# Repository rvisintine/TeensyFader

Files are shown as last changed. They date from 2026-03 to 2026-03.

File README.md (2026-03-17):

# USB MIDI Crossfader

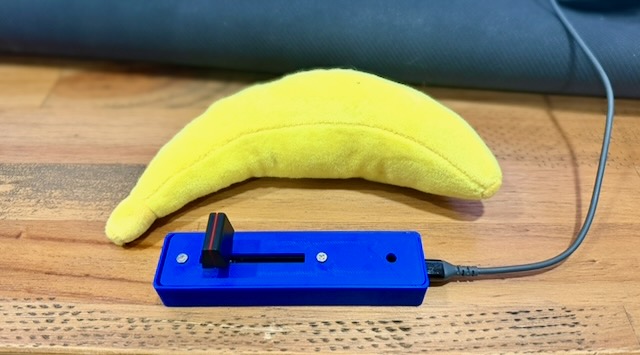
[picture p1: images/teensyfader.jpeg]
Teensy Fader


I wanted a simple MIDI crossfader for using with Traktor and Ableton.  I couldn't find anything I liked so decided to build my own.  The Mini Innofader Plus I used is way overkill, you could swap it out with something cheaper. It should work just fine with the Teensy code as is, you'd just need to tweak the case to fit whatever you buy.  You'll need some basic soldering tools and skills, and a 3d printer to complete this project.

## Materials

To build this you'll need to buy
Mini Innofader Plus ($115 shipped) [innofader.com](https://www.innofader.com/products.php?id=24)

Teensy 4.0 (without pins) ~$23 [sparkfun.com](https://www.sparkfun.com/teensy-4-0.html) |

Optional:
WS2812B NeoPixel LED (single)
Adhesive rubber feet

## Wiring

The Mini Innofader Plus includes multiple harnesses.  I used one of the 3-wire harnesses (gray, green, blue). The fader has
auto-sensing polarity, so the outer two wires (VCC/GND) can be swapped without damage.
The center wire (green) is always the wiper/signal.

| Wire | Color | Teensy 4.0 Pin |
|---|---|---|
| VCC | Gray | 3.3V |
| Wiper (signal) | Green (center) | A0 (pin 14) |
| GND | Blue | GND |

**WS2812B LED** (optional):

| LED Wire | Teensy 4.0 Pin |
|---|---|
| GND | GND |
| DIN (data in) | Pin 2 |
| VCC | 3.3V |

## Firmware

### Requirements

- [Arduino IDE](https://www.arduino.cc/en/software)
- [Teensyduino](https://www.pjrc.com/teensy/td_download.html) add-on — follow the install guide on the Teensyduino page for your platform
- [Adafruit NeoPixel](https://github.com/adafruit/Adafruit_NeoPixel) library — Arduino IDE may prompt to install this automatically when you open the sketch; otherwise install via **Sketch > Include Library > Manage Libraries**
### Flashing

1. Open `firmware/crossfader.ino` in Arduino IDE
2. Select **Board: Teensy 4.0**
3. Select **USB Type: Serial + MIDI**
4. Click Upload

### Configuration (via Serial)

Settings can be changed in code before uploading, or can be changed over serial and saved to EEPROM (persists across power cycles).
Open any serial terminal at 9600 baud — Arduino Serial Monitor works fine.

When connected, the device prints its current config automatically.

| Command | Description |
|---|---|
| `channel <1-16>` | Set MIDI channel |
| `cc <0-127>` | Set fader CC number |
| `ledcc <0-127>` | Set incoming CC number for LED color |
| `status` | Print current config |

## Testing

Once the firmware is flashed and the fader is wired up, you can validate that everything
works before connecting to your software.

### MIDI Monitor

[MIDI Monitor](https://www.snoize.com/midimonitor/) is a free macOS app that displays
all incoming MIDI messages in real time.  You should be able to use something like MidiView for PC.

1. Install and open MIDI Monitor
2. Plug in the Teensy via USB — it should appear as a MIDI source named "Teensy MIDI"
3. Select the source in MIDI Monitor's sources list
4. Move the fader — you should see **Control Change** messages scrolling as you move it
5. The CC number and channel should match your configured values (defaults: CC 4, channel 20)
6. Values should range smoothly from 0 (one end) to 127 (other end)

### Troubleshooting

- **No MIDI device appears** — make sure the firmware was flashed with **USB Type: Serial + MIDI**. If you used a different USB type, reflash with the correct setting.
- **Device appears but no messages** — check the wiring. The signal wire (green/center) must be connected to **A0**. Verify VCC and GND are connected to **3.3V** and **GND**.
- **Values jump or are noisy** — this can indicate a loose solder joint on the wiper (signal) wire. Reflow the connection.
- **Values only go partway** — the fader travel may not reach the full range. This is normal for some innofader models and can be adjusted in the firmware's ADC mapping if needed.
- **Teensy not recognized by macOS** — try a different USB cable (some cables are charge-only with no data lines). Try a different USB port.

## Enclosure

Open `enclosure/crossfader_case.scad` in [OpenSCAD](https://openscad.org/) to render and export STL files.

The enclosure is a two-piece design:

- **Base** — full-height box with internal support for the lid, USB port cutout, and a friction-fit Teensy cradle with L-shaped rails and SMD clearance underneath
- **Lid** — hollow shell with fader slot, M3 mounting holes, and optional LED hole; drops into the base

All dimensions are parametric — adjust fader and Teensy measurements at the top of the SCAD file to fit your specific components.

### Print Settings

- Layer height: 0.2mm
- Infill: 20%
- Material: PLA or PETG
- Supports: none needed (both pieces print flat)

**Bambu Studio note:** After importing the STL, split the parts and flip the lid 180 degrees so the top surface sits flat on the build plate. The SCAD file exports both pieces upright, but the lid needs to print top-down.

## RGB LED (Optional)

The LED lights red on power-up. Software (e.g., Traktor) can change the color by sending
a MIDI CC message back to the device on the configured LED CC number (default: CC 2).

| CC Value | Color |
|---|---|
| 0-15 | Red |
| 16-31 | Green |
| 32-47 | Blue |
| 48-63 | Yellow |
| 64-79 | Cyan |
| 80-95 | Magenta |
| 96-111 | White |
| 112-127 | Off |

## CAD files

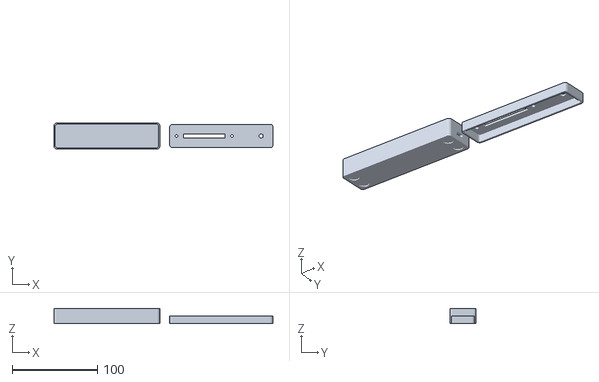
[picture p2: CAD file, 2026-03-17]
enclosure/crossfader_case.stl
256.5 x 30.4 x 18.0

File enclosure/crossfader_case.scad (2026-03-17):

// USB MIDI Crossfader — Enclosure
// Two-piece snap-fit case for Mini Innofader Plus + Teensy 4.0
// Print both pieces flat (no supports needed).
//
// Units: mm

// --- Dimensions (adjust to match your specific Innofader Plus) ---
fader_slot_length = 49;       // fader knob travel opening
fader_slot_width  = 5;        // width of the slot for the knob
fader_mount_spacing = 65;     // screw hole center-to-center (~1.5")
fader_mount_hole_dia = 3.2;   // M3 screw clearance
fader_body_length = 73;       // fader PCB length (along travel axis)
fader_body_width  = 16;       // fader PCB width

// Teensy 4.0 dimensions (without pins — soldering wires directly)
teensy_length = 36.3;
teensy_width  = 17.4;
teensy_height = 4;            // no pins, board + components only
usb_width     = 8;            // micro-USB port opening
usb_height    = 3.0;            // micro-USB port height

// Teensy cradle parameters
teensy_cradle_tolerance = 0.3;      // gap per side for friction fit
teensy_ledge_height = 2.5;          // height of ledge where PCB rests (SMD clearance below)
teensy_rail_total_height = 4.5;     // total rail height (extends above ledge to grip board)
teensy_rail_thickness = 1.5;        // outer rail wall thickness
teensy_ledge_width = 1.0;           // inward lip width that supports PCB edges
teensy_backstop_thickness = 1.5;    // end stop wall thickness

// Case parameters
wall = 2;
case_length = fader_body_length + teensy_length + wall * 3 + 5; // fader + gap + teensy
case_width  = max(fader_body_width, teensy_width) + wall * 2 + 6;
case_height = 18;             // raised for component clearance
corner_r    = 3;
fit_gap     = 3.0;            // base larger than top plate (1.5mm per side)
lid_clearance = 0.2;          // clearance around lid in rebate (0.1mm per side)
lower_wall = wall + 1.0;      // thicker walls below rebate to create wider ledge (3mm)

// Teensy area position (shared between base and top_plate)
teensy_area_start = wall + 2 + fader_body_length + wall + 5;

// LED hole (for WS2812B — light pipe or flush mount)
led_hole_dia = 5;

// Rubber foot recesses
foot_dia    = 10;
foot_depth  = 1;
foot_inset  = 8; // from corner

// --- Modules ---

module rounded_box(l, w, h, r) {
    hull() {
        for (x = [r, l-r])
            for (y = [r, w-r])
                translate([x, y, 0])
                    cylinder(h=h, r=r, $fn=30);
    }
}

// (snap-fit removed — lid friction-fits into rebate)

// --- Base (full-height box with rebate for lid) ---
module base() {
    off = fit_gap / 2;  // base extends this far beyond top plate on each side
    base_length = case_length + fit_gap;
    base_width  = case_width + fit_gap;

    difference() {
        // Outer shell — full case height
        translate([-off, -off, 0])
            rounded_box(base_length, base_width, case_height, corner_r);

        // Lower cavity (component area — thicker walls for ledge)
        translate([-off + lower_wall, -off + lower_wall, wall])
            rounded_box(base_length - lower_wall*2, base_width - lower_wall*2,
                        case_height, corner_r - 1);

        // Upper rebate (lid drops in here — thinner rim walls)
        translate([-lid_clearance/2, -lid_clearance/2, case_height / 2])
            rounded_box(case_length + lid_clearance, case_width + lid_clearance,
                        case_height, corner_r - 0.5);

        // USB port cutout (through base back wall — aligned to Teensy on ledge)
        usb_z = wall + teensy_ledge_height + 1.2;
        translate([case_length - wall - 1,
                   case_width/2 - usb_width/2,
                   usb_z])
            cube([wall + off + 2, usb_width, usb_height]);

        // Rubber foot recesses (bottom, centered on base)
        for (x = [foot_inset - off, base_length - foot_inset - off])
            for (y = [foot_inset - off, base_width - foot_inset - off])
                translate([x, y, -0.01])
                    cylinder(d=foot_dia, h=foot_depth, $fn=30);
    }

    // Teensy cradle — L-shaped rails with ledges, open underneath for SMDs
    teensy_cavity_width = teensy_width + teensy_cradle_tolerance * 2;
    teensy_center_y = case_width / 2;
    teensy_rail_y_left  = teensy_center_y - teensy_cavity_width / 2 - teensy_rail_thickness;
    teensy_rail_y_right = teensy_center_y + teensy_cavity_width / 2;
    teensy_rail_len = teensy_length - 6;  // shortened on USB end for clearance

    // Left rail wall (full height)
    translate([teensy_area_start, teensy_rail_y_left, wall])
        cube([teensy_rail_len, teensy_rail_thickness, teensy_rail_total_height]);

    // Left rail ledge (inward lip — PCB edge rests here)
    translate([teensy_area_start, teensy_rail_y_left + teensy_rail_thickness, wall])
        cube([teensy_rail_len, teensy_ledge_width, teensy_ledge_height]);

    // Right rail wall (full height)
    translate([teensy_area_start, teensy_rail_y_right, wall])
        cube([teensy_rail_len, teensy_rail_thickness, teensy_rail_total_height]);

    // Right rail ledge (inward lip — PCB edge rests here)
    translate([teensy_area_start, teensy_rail_y_right - teensy_ledge_width, wall])
        cube([teensy_rail_len, teensy_ledge_width, teensy_ledge_height]);

    // Backstop (non-USB end, prevents sliding toward fader)
    translate([teensy_area_start - teensy_backstop_thickness,
               teensy_rail_y_left,
               wall])
        cube([teensy_backstop_thickness,
              teensy_cavity_width + teensy_rail_thickness * 2,
              teensy_rail_total_height]);
}

// --- Top plate (lid — drops into base rebate) ---
module top_plate() {
    fader_area_start = wall + 2;

    difference() {
        // Lid outer shell
        rounded_box(case_length, case_width, case_height / 2, corner_r);

        // Hollow out underside (fader body hangs down into this cavity)
        translate([wall, wall, -0.01])
            rounded_box(case_length - wall*2, case_width - wall*2,
                        case_height / 2 - wall + 0.01, corner_r - 1);

        // Fader slot (knob travel)
        translate([fader_area_start + (fader_body_length - fader_slot_length) / 2,
                   case_width/2 - fader_slot_width/2,
                   -0.5])
            cube([fader_slot_length, fader_slot_width, case_height]);

        // Fader mounting holes (M3 clearance through 2mm ceiling)
        fader_center_x = fader_area_start + fader_body_length / 2;
        for (dx = [-fader_mount_spacing/2, fader_mount_spacing/2])
            translate([fader_center_x + dx, case_width/2, -0.5])
                cylinder(d=fader_mount_hole_dia, h=case_height, $fn=30);

        // LED hole (near the USB end)
        translate([case_length - wall - 12, case_width/2, -0.5])
            cylinder(d=led_hole_dia, h=case_height, $fn=30);
    }
}

// --- Render ---
// Base
base();

// Top plate / lid (offset for printing — move next to base)
translate([case_length + fit_gap + 10, 0, 0])
    top_plate();

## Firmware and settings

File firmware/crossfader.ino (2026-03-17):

// USB MIDI Crossfader — Teensy 4.0 Firmware
// Reads a Mini Innofader Plus on analog pin A0 and sends MIDI CC messages.
// RGB LED (WS2812B) shows power status and responds to incoming MIDI.
// Configuration via serial terminal (channel, cc, led cc saved to EEPROM).
//
// Build: Arduino IDE + Teensyduino
//   Board: Teensy 4.0
//   USB Type: Serial + MIDI
//
// Requires: Adafruit NeoPixel library (install via Library Manager)

#include <EEPROM.h>
#include <Adafruit_NeoPixel.h>

// --- EEPROM addresses ---
const int EEPROM_MAGIC   = 0;
const int EEPROM_CHANNEL = 1;
const int EEPROM_CC      = 2;
const int EEPROM_LED_CC  = 3;
const byte EEPROM_MAGIC_VALUE = 0xCF;

// --- Defaults ---
const int DEFAULT_CHANNEL = 4;
const int DEFAULT_CC      = 20;
const int DEFAULT_LED_CC  = 69;  // incoming CC to control LED color

// --- Options ---
const bool HEARTBEAT_ENABLED = true; // set to false to disable onboard LED heartbeat

// --- Pins ---
const int FADER_PIN = A0;
const int LED_PIN   = 2;      // WS2812B data pin (any digital pin works)
const int ONBOARD_LED_PIN = 13; // Teensy 4.0 onboard LED (orange, single color)

// --- LED color presets (matched by incoming CC value ranges) ---
// CC 0-15: red (default/power)    CC 16-31: green
// CC 32-47: blue                  CC 48-63: yellow
// CC 64-79: cyan                  CC 80-95: magenta
// CC 96-111: white                CC 112-127: off
const int NUM_PRESETS = 8;
const uint32_t COLOR_PRESETS[] = {
  0xFF0000,  // 0:  red
  0x00FF00,  // 1:  green
  0x0000FF,  // 2:  blue
  0xFFFF00,  // 3:  yellow
  0x00FFFF,  // 4:  cyan
  0xFF00FF,  // 5:  magenta
  0xFFFFFF,  // 6:  white
  0x000000   // 7:  off
};

// --- NeoPixel ---
Adafruit_NeoPixel led(1, LED_PIN, NEO_GRB + NEO_KHZ800);

// --- Runtime config (loaded from EEPROM) ---
int midiChannel;
int midiCC;
int ledCC;

// --- Smoothing / jitter suppression ---
const int SMOOTH_WINDOW = 4;
const int CHANGE_THRESHOLD = 1;

int readings[SMOOTH_WINDOW];
int readIndex = 0;
long readTotal = 0;
int lastSentValue = -1;

// --- Serial input buffer ---
char serialBuf[32];
int serialPos = 0;

void setLED(uint32_t color) {
  led.setPixelColor(0, color);
  led.show();
}

void loadConfig() {
  if (EEPROM.read(EEPROM_MAGIC) == EEPROM_MAGIC_VALUE) {
    midiChannel = constrain(EEPROM.read(EEPROM_CHANNEL), 1, 16);
    midiCC = constrain(EEPROM.read(EEPROM_CC), 0, 127);
    ledCC = constrain(EEPROM.read(EEPROM_LED_CC), 0, 127);
  } else {
    midiChannel = DEFAULT_CHANNEL;
    midiCC = DEFAULT_CC;
    ledCC = DEFAULT_LED_CC;
    saveConfig();
  }
}

void saveConfig() {
  EEPROM.update(EEPROM_MAGIC, EEPROM_MAGIC_VALUE);
  EEPROM.update(EEPROM_CHANNEL, midiChannel);
  EEPROM.update(EEPROM_CC, midiCC);
  EEPROM.update(EEPROM_LED_CC, ledCC);
}

void printConfig() {
  Serial.println("--- MIDI Crossfader ---");
  Serial.print("  channel: ");
  Serial.println(midiChannel);
  Serial.print("  cc:      ");
  Serial.println(midiCC);
  Serial.print("  ledcc:   ");
  Serial.println(ledCC);
  Serial.println();
  Serial.println("Commands:");
  Serial.println("  channel <1-16>    MIDI channel");
  Serial.println("  cc <0-127>        fader CC number");
  Serial.println("  ledcc <0-127>     incoming CC for LED color");
  Serial.println("  status            print config");
  Serial.println();
  Serial.println("LED colors (by incoming CC value):");
  Serial.println("  0-15: red    16-31: green   32-47: blue");
  Serial.println("  48-63: yellow  64-79: cyan  80-95: magenta");
  Serial.println("  96-111: white  112-127: off");
}

void processCommand(const char* cmd) {
  int value;

  if (sscanf(cmd, "channel %d", &value) == 1) {
    if (value >= 1 && value <= 16) {
      midiChannel = value;
      saveConfig();
      Serial.print("Channel set to ");
      Serial.println(midiChannel);
    } else {
      Serial.println("Error: channel must be 1-16");
    }
  } else if (sscanf(cmd, "ledcc %d", &value) == 1) {
    if (value >= 0 && value <= 127) {
      ledCC = value;
      saveConfig();
      Serial.print("LED CC set to ");
      Serial.println(ledCC);
    } else {
      Serial.println("Error: ledcc must be 0-127");
    }
  } else if (sscanf(cmd, "cc %d", &value) == 1) {
    if (value >= 0 && value <= 127) {
      midiCC = value;
      saveConfig();
      Serial.print("CC set to ");
      Serial.println(midiCC);
    } else {
      Serial.println("Error: cc must be 0-127");
    }
  } else if (strncmp(cmd, "status", 6) == 0) {
    printConfig();
  } else {
    Serial.print("Unknown command: ");
    Serial.println(cmd);
    printConfig();
  }
}

void handleIncomingMIDI() {
  // Process all pending MIDI messages
  while (usbMIDI.read()) {
    if (usbMIDI.getType() == usbMIDI.ControlChange &&
        usbMIDI.getChannel() == midiChannel &&
        usbMIDI.getData1() == ledCC) {
      int value = usbMIDI.getData2();
      int preset = (value * NUM_PRESETS) / 128; // map 0-127 to preset index
      preset = constrain(preset, 0, NUM_PRESETS - 1);
      setLED(COLOR_PRESETS[preset]);
    }
  }
}

void setup() {
  Serial.begin(9600);
  analogReadResolution(12); // Teensy 4.0: 12-bit ADC (0-4095)

  pinMode(ONBOARD_LED_PIN, OUTPUT);

  led.begin();
  led.setBrightness(30); // keep it subtle — adjust 0-255

  loadConfig();
  setLED(COLOR_PRESETS[0]); // red on boot

  for (int i = 0; i < SMOOTH_WINDOW; i++) {
    readings[i] = analogRead(FADER_PIN);
    readTotal += readings[i];
  }

  delay(500);
  printConfig();
}

void loop() {
  // --- Read fader ---
  readTotal -= readings[readIndex];
  readings[readIndex] = analogRead(FADER_PIN);
  readTotal += readings[readIndex];
  readIndex = (readIndex + 1) % SMOOTH_WINDOW;

  int smoothed = readTotal / SMOOTH_WINDOW;
  int mapped = map(smoothed, 0, 4095, 0, 127);
  mapped = constrain(mapped, 0, 127);

  if (lastSentValue < 0 || abs(mapped - lastSentValue) > CHANGE_THRESHOLD) {
    usbMIDI.sendControlChange(midiCC, mapped, midiChannel);
    lastSentValue = mapped;
  }

  // --- Handle serial commands ---
  while (Serial.available()) {
    char c = Serial.read();
    if (c == '\n' || c == '\r') {
      if (serialPos > 0) {
        serialBuf[serialPos] = '\0';
        processCommand(serialBuf);
        serialPos = 0;
      }
    } else if (serialPos < (int)sizeof(serialBuf) - 1) {
      serialBuf[serialPos++] = c;
    }
  }

  // --- Handle incoming MIDI (LED control) ---
  handleIncomingMIDI();

  // --- Onboard LED heartbeat (~2 second breathing cycle) ---
  if (HEARTBEAT_ENABLED) {
    int brightness = (millis() / 8) % 256;
    if (brightness > 127) brightness = 255 - brightness;
    analogWrite(ONBOARD_LED_PIN, brightness);
  }

  delay(1);
}
